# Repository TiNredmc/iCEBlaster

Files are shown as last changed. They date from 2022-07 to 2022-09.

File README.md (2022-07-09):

# iCEBlaster

iCEBlaster. STM32 based iCE40 SPI bitstream loader tool with USB MSC Drag and Drop feature.

# Description

iCEBlaster is a Drag and Drop firmware loader via SPI for iCE40 FPGA. The brain of this project is based on STM32F042F6P6 Arm Cortex M0 microcontroller.

By using USB-FS library working as USB Mass storage device class (USB MSC) and with Virtual file system based on FAT12. Working together as USB Disk pre formatted with FAT12 file system with 512 Bytes per sector, 65535 total sectors, 4 sectors reserved for master boot record (sector 0) and File allocation tables(sector 1, 2 and 3). No longer use internal flash as medium storage. 
By copying the iCE40 FPGA Bitstream to the disk, 2 for loops in state machine inside STORAGE_Write_FS() receive data from USB buffer and send it over SPI in chucks of 512 bytes to FPGA. With this technique, no Internal flash is required. 

The iCE40's Bitstream loading sequence is something like this 
```
// Reset and enter SPI mode sequence.
1. Pull SPI CE Pin to Low
2. Pull CRESET Pin to Low
3. Wait for 2ms.
4. Release CRESET (to HIGH). At this point iCE40 is now in Slave SPI mode.
5. wait for 200ms to make sure iCE40's Configuration RAM (CRAM) is cleared.

// Bitstream loading sequence.
6. Sending Bitstream data via SPI bus (MSB first for each byte).
7. Send 12 dummy bytes (0x00).
8. (optional) Send 7 dummy bytes (0x00) and the SPI pin can be later reconfigure to use as normal PIO

// End of loading.
9. Release SPI CE Pin (to HIGH). The iCE40 will automagically start.
```

When done, The mcu release CRESET to let FPGA run the firmware that we just flash. Then perform the USB reconnect to have a new and ready to Drag and Drop USB Disk.

# Link(s)

[Hackaday.io](https://hackaday.io/project/185263-iceblaster)

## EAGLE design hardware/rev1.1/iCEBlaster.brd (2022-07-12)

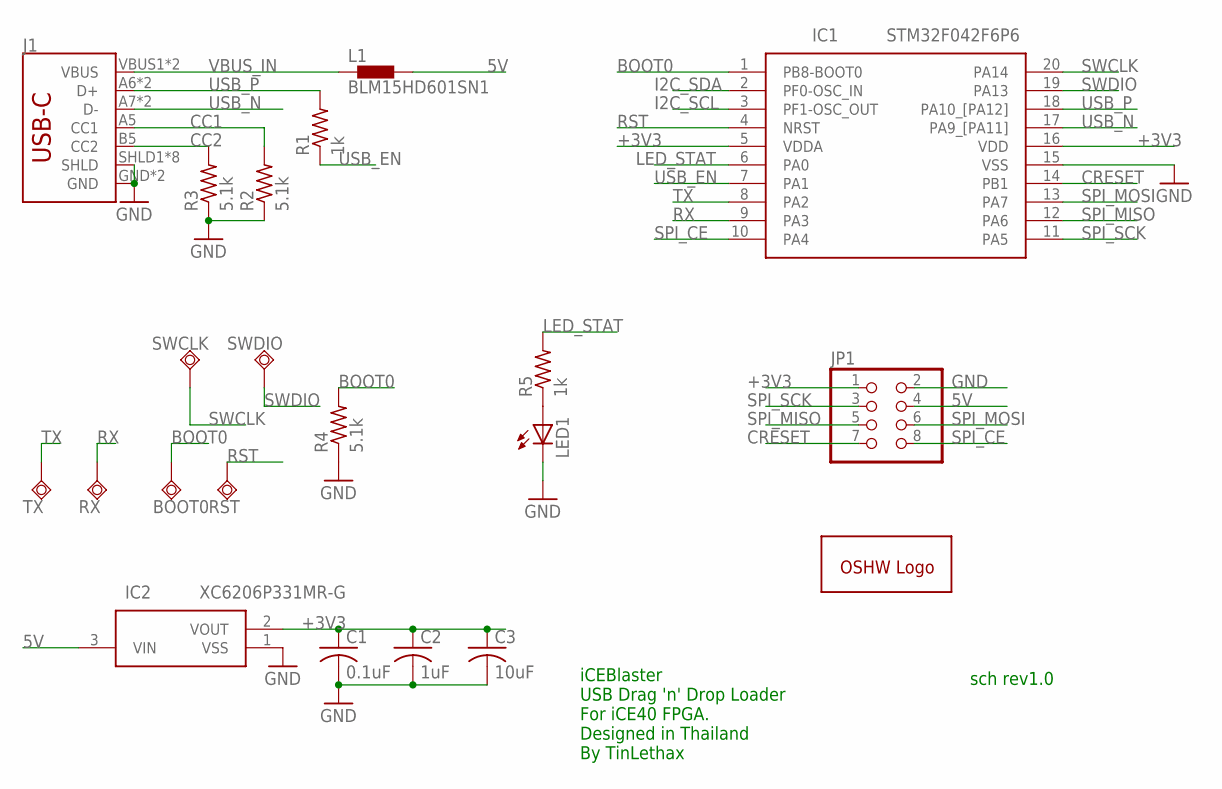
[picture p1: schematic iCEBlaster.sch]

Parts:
BOOT0: TPSQTP15SQ; TP15SQ
C1: 0.1uF; C0603
C2: 1uF; C0603
C3: 10uF; C0603
GOLD_ORB_SM1: OSHWLOGOLOGO5MM; OSHW_5MM
IC1: STM32F042F6P6; SOP65P640X120-20N
IC2: XC6206P331MR-G; SOT95P280X130-3N
J1: SPARKFUN-CONNECTORS_USB_C16PIN; SPARKFUN-CONNECTORS_USB-C-16P
JP1: PINHD-2X4/90; 2X04/90
L1: BLM15HD601SN1; 0402
LED1: LEDCHIP-LED0603; CHIP-LED0603
R1, R5: 1k; R0603
R2, R3, R4: 5.1k; R0603
RST: TPSQTP15SQ; TP15SQ
RX: TPSQTP15SQ; TP15SQ
SWCLK: TPSQTP15SQ; TP15SQ
SWDIO: TPSQTP15SQ; TP15SQ
TX: TPSQTP15SQ; TP15SQ

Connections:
5V: IC2.3 (VIN), JP1.4, L1.2
+3V3: C1.1, C2.1, C3.1, IC1.5 (VDDA), IC1.16 (VDD), IC2.2 (VOUT), JP1.1
BOOT0: BOOT0.TP, IC1.1 (PB8-BOOT0), R4.2
CC1: J1.A5 (CC1), R2.2
CC2: J1.B5 (CC2), R3.2
CRESET: IC1.14 (PB1), JP1.7
GND: C1.2, C2.2, C3.2, IC1.15 (VSS), IC2.1 (VSS), J1.GND, J1.GND2 (GND), J1.SHLD1 (SHLD), J1.SHLD2 (SHLD), J1.SHLD3 (SHLD), J1.SHLD4 (SHLD), J1.SHLD5 (SHLD), J1.SHLD6 (SHLD), J1.SHLD7 (SHLD), J1.SHLD8 (SHLD), JP1.2, LED1.C, R2.1, R3.1, R4.1
I2C_SCL: IC1.3 (PF1-OSC_OUT)
I2C_SDA: IC1.2 (PF0-OSC_IN)
LED: LED1.A, R5.1
LED_STAT: IC1.6 (PA0), R5.2
RST: IC1.4 (NRST), RST.TP
RX: IC1.9 (PA3), RX.TP
SPI_CE: IC1.10 (PA4), JP1.8
SPI_MISO: IC1.12 (PA6), JP1.5
SPI_MOSI: IC1.13 (PA7), JP1.6
SPI_SCK: IC1.11 (PA5), JP1.3
SWCLK: IC1.20 (PA14), SWCLK.TP
SWDIO: IC1.19 (PA13), SWDIO.TP
TX: IC1.8 (PA2), TX.TP
USB_EN: IC1.7 (PA1), R1.1
USB_N: IC1.17 (PA9_[PA11]), J1.A7 (D-), J1.B7 (D-)
USB_P: IC1.18 (PA10_[PA12]), J1.A6 (D+), J1.B6 (D+), R1.2
VBUS_IN: J1.VBUS1 (VBUS), J1.VBUS2 (VBUS), L1.1

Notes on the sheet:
iCEBlaster USB Drag 'n' Drop Loader For iCE40 FPGA. Designed in Thailand By TinLethax
sch rev1.0

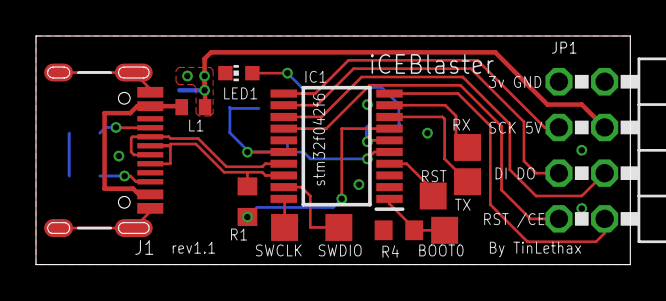
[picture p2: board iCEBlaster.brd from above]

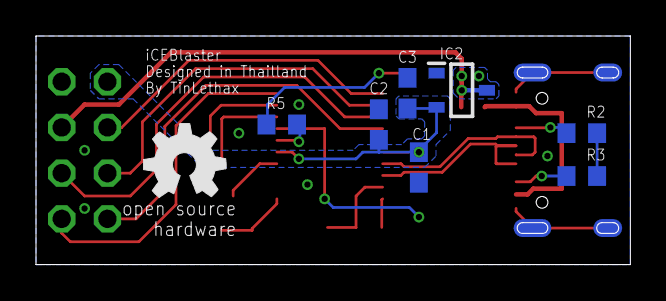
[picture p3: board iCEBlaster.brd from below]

Board: 2 copper layers, 33.0 x 12.7 mm, 21 parts (8 on the bottom side), 22 nets.

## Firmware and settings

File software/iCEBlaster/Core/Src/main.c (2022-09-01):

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
/* Includes ------------------------------------------------------------------*/
#include "main.h"
#include "usb_device.h"

/* USER CODE BEGIN Includes */
#include <stdint.h>
/* USER CODE END Includes */

SPI_HandleTypeDef hspi1;

/* USER CODE BEGIN PV */
uint8_t reset_flag;
/* USER CODE END PV */

void SystemClock_Config(void);
static void MX_GPIO_Init(void);
static void MX_SPI1_Init(void);
/**
  * @brief  The application entry point.
  * @retval int
  */
int main(void)
{
  /* MCU Configuration--------------------------------------------------------*/

  /* Reset of all peripherals, Initializes the Flash interface and the Systick. */
  HAL_Init();

  /* Configure the system clock */
  SystemClock_Config();

  /* Initialize all configured peripherals */
  MX_GPIO_Init();
  MX_SPI1_Init();
  MX_USB_DEVICE_Init();
  /* USER CODE BEGIN 2 */
  HAL_GPIO_WritePin(SPI1_CE_GPIO_Port, SPI1_CE_Pin, 1);// Release SPI CE.
  HAL_GPIO_WritePin(CRESET_GPIO_Port, CRESET_Pin, 1);// Release FPGA's CRESET.
  HAL_GPIO_WritePin(USB_EN_GPIO_Port, USB_EN_Pin, 1);// Enable USB pull up to enumerate USB. By release open drain output
  HAL_GPIO_WritePin(LED_STAT_GPIO_Port, LED_STAT_Pin, 1);// Turn Status LED on.
  /* USER CODE END 2 */

  /* Infinite loop */
  /* USER CODE BEGIN WHILE */
  while (1)
  {
    /* USER CODE END WHILE */

    /* USER CODE BEGIN 3 */
	  if(reset_flag == 1){// if receive USB reset flag after Bitstream loaded.
		  // Auto USB reconnect.
		  HAL_Delay(200);
		  HAL_GPIO_WritePin(USB_EN_GPIO_Port, USB_EN_Pin, 0);
		  HAL_Delay(100);
		  HAL_GPIO_WritePin(USB_EN_GPIO_Port, USB_EN_Pin, 1);
		  reset_flag = 0;
	  }
  }
  /* USER CODE END 3 */
}

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


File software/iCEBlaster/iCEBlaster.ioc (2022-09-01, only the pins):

Mcu.UserName=STM32F042F6Px
PA0.GPIO_Label=LED_STAT
PA0.Signal=GPIO_Output
PA1.GPIO_Label=USB_EN
PA1.Signal=GPIO_Output
PA11.Signal=USB_DM
PA12.Signal=USB_DP
PA13.Signal=SYS_SWDIO
PA14.Signal=SYS_SWCLK
PA4.GPIO_Label=SPI1_CE
PA4.Signal=GPIO_Output
PA5.Signal=SPI1_SCK
PA6.Signal=SPI1_MISO
PA7.Signal=SPI1_MOSI
PB1.GPIO_Label=CRESET
PB1.Signal=GPIO_Output

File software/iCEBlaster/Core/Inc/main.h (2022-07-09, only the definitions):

#define LED_STAT_Pin GPIO_PIN_0
#define LED_STAT_GPIO_Port GPIOA
#define USB_EN_Pin GPIO_PIN_1
#define USB_EN_GPIO_Port GPIOA
#define SPI1_CE_Pin GPIO_PIN_4
#define SPI1_CE_GPIO_Port GPIOA
#define CRESET_Pin GPIO_PIN_1
#define CRESET_GPIO_Port GPIOB

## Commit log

2022-07-12 Added rev1.1 PCB.
    [iCEBlaster.brd, iCEBlaster.sch]
2022-09-01 iCEBlaster is now working!!
    - Tested with STM32F042F4P6.
    - Switch back to use switch case state machine instead of old crappy implementation that aim to
    save code space.
    - Changed block number to 510 to match with the File system.
    - Volume label is now working properly.

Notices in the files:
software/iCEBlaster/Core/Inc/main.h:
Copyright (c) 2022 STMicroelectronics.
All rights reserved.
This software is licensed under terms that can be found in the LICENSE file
